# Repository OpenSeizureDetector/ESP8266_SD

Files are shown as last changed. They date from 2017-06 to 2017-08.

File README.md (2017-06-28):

# Seizure Detector Watch using DIY Hardware

A version of OpenSeizureDetector that runs on an ESP8266 wifi module.

# The Plan
*  Use a very small ESP8226 module
*  Connect an ADXL345 accelerometer using i2c interface
*  Power it from a LiPo battery
*  Use a 3D printed case to make it into a watch  
*  Software will use the esp-open-rtos FreeRTOS based ESP8266 SDK so it can be ported to other platforms more easily in the future (https://github.com/SuperHouse/esp-open-rtos).
*  Initially it will provide a web server to act as an OpenSeizureDetector 'Network Datasource' (this is likely to be too power hungry so I think we will change it to push data over wifi rather than wait for clients to ask for it in the future).

# Hardware Parts
## Feasibility and Proof-of-Concept Version
* Wemos D1 Mini ESP8226 board, with on-board USB for debugging (http://www.ebay.co.uk/itm/322463251729?_trksid=p2060353.m2749.l2649&ssPageName=STRK%3AMEBIDX%3AIT) (£5.80)
* ADXL345 module (http://www.ebay.co.uk/itm/142166117195?_trksid=p2060353.m2749.l2649&ssPageName=STRK%3AMEBIDX%3AIT) (£2.82)

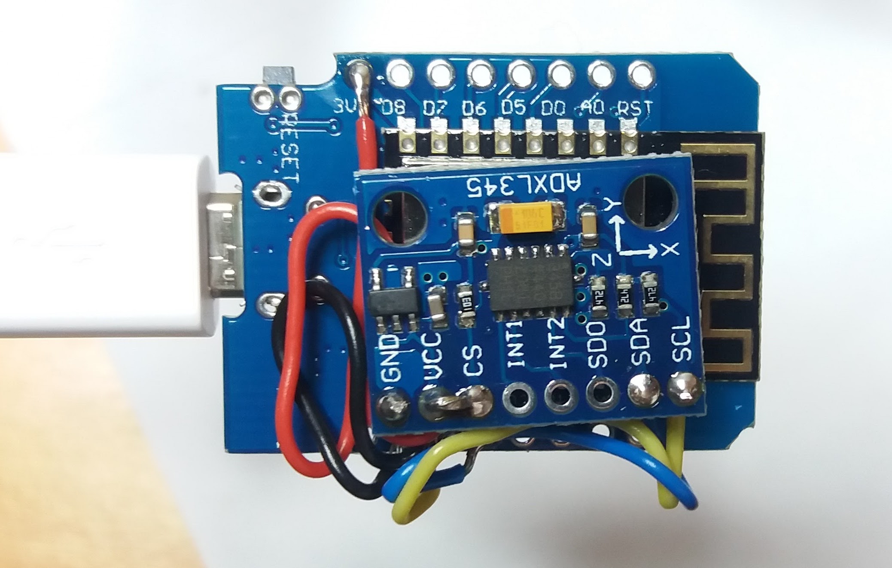
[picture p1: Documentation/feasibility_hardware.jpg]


## Prototype Version
* Small ESP8266 Board - ESP-12F (http://www.ebay.co.uk/itm/282412004710?_trksid=p2060353.m2749.l2649&ssPageName=STRK%3AMEBIDX%3AIT) (£2.52)
* ADXL345 Individual IC (http://www.ebay.co.uk/itm/132189086693?_trksid=p2060353.m2749.l2649&ssPageName=STRK%3AMEBIDX%3AIT) (£1.35)
* LiPo Battery (don't know which yet)

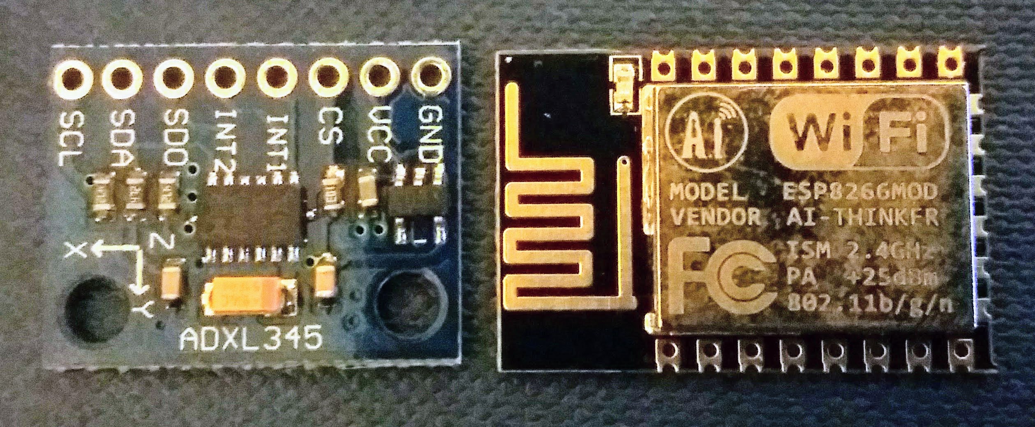
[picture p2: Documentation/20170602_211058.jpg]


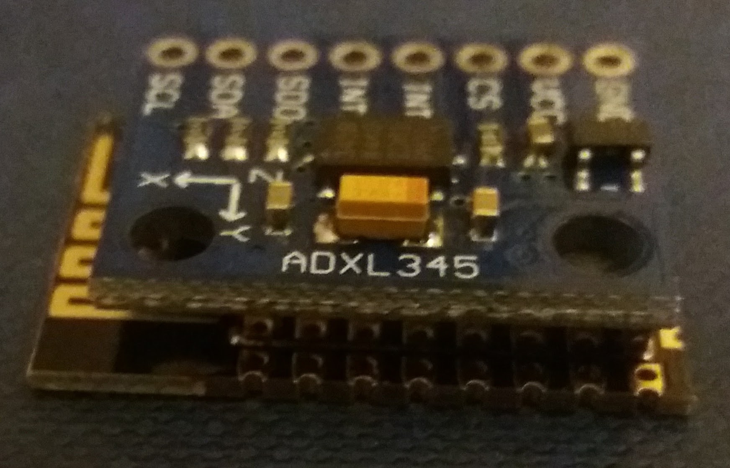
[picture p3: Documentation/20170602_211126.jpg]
Stacked Modules


# Hardware Connections
## Connect ADXL345 accelerometer to ESP8226
*  SCL  - GPIO5  (D1 on Wemos D1 Mini module)
*  SDA  - GPIO4  (D2 on Wemos D1 Mini module)
*  INT1 - GPIO13 (D7 on Wemos D1 Mini module)
*  3.3V
*  GND

No external resistors etc. are necessary.

# Development Plan
## Fesibility Study
*  Use esp-open-rtos Software Development Kit (https://github.com/SuperHouse/esp-open-rtos).
*  Use the i2c library included in the SDK.
*  Port the Arduino ADXL345 library to C and convert to use the i2c library (Complete).
*  Extend the ADXL345 library to use the FIFO register in the ADXL345 so we
   receive data in batches to save power (Complete)
*  Port the OpenSeizureDetector Pebble_SD code to use the new library, and send output to serial port for debugging (complete)
*  Add web server to prove ESP8266 capable of running seizure detector and networking simultaneously.

## Proof-of-Concept
*  Make web server act as an OpenSeizureDetector Network DataSource (in progress)
*  Test battery consumption
*  Optimise code to make battery power feasible (may involve changing from web server to ESP8266 sending data to OpenSeizureDetector alarm system)
*  Select rechargeable battery.

## Prototype
*  Make programmer hardware for ESP-12F module
*  Hand wire ADXL345 chip to ESP-12F module  
*  Connect battery
*  Design and build battery charging hardware.
*  Test
*  Produce 3D printed watch case.

# Instructions
Note that this is just at proof-of-concpt stage - don't expect it to
produce a working seizure detector!

*  Install the esp-open-rtos SDK using the instructions at https://github.com/SuperHouse/esp-open-rtos
*  Compile using
  *  cd osd_app
  *  make html  (prepare test data for web server)
  *  make  (compile software)
  *  make flash (to programme ESP8266 connected via USB)
  *  ../monitor.py (to view debugging information over serial (USB) interface).
  *  Press the reset button on the ESP8266 to view boot up and initialisation debugging information.

# Debugging
If the ESP8266 crashes because of a software bug (Such as divide by zero),
debugging information is written to the USB serial line that you can see
using monitor.py

You can find information on interpreting the crash dump at https://github.com/SuperHouse/esp-open-rtos/wiki/Crash-Dumps.

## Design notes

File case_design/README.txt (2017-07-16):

design of case for seizure detector watch

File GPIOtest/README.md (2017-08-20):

##GPIOtest
Prove we can program a Wemos D1 ESP8266 board using espressif SDK and use
GPIO.

Compile Using
source ../set_paths.sh
make
../flash_image.sh

Should flash the LED on the board....

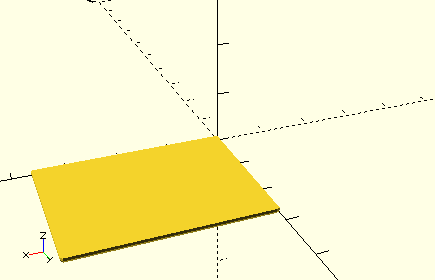
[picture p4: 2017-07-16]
case_design/lid.png

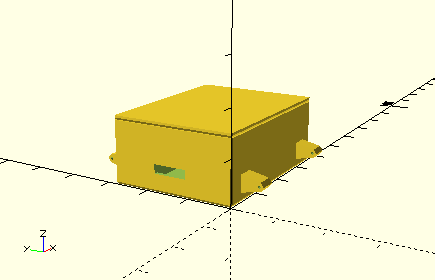
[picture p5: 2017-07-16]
case_design/case.png

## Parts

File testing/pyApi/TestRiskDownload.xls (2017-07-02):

0 | 1 | 2 | 3 | 4 | 5 | 6 | 7 | 8 | 9 | 10 | 11 | 12 | 13 | 14 | 15 | 16 | 17 | 18 | 19 | 20 | 21 | 22 | 23 | 24 | 25 | 26 | 27 | 28 | 29 | 30 | 31 | 32 | 33 | 34 | 35 | 36 | 37 | 38 | 39 | 40 | 41 | 42 | 43 | 44 | 45 | 46 | 47 | 48 | 49 | 50 | 51 | 52 | 53 | 54 | 55 | 56 | 57 | 58 | 59
Risk ID | Risk no | Parent risk id | Risk owner name | Risk owner BU | Risk title | Risk description | Risk timescales | Plant | Failure type | Lifetime issue | Problem type | Risk status | Business unit list | EPRI code list | Reactor | Risk last updated for KPI | Risk comments | Risk cause list | Risk consequences | Risk type list | Risk restricted | GRMC | CR no | Risk originator | Risk originated date | Inherent % | EPRI Code | Earliest event can happened | Latest event can happen | Most likely impact risk | Most units affected Risk | Most load reduction risk | Most downtime risk | Most cost repair risk | Most cost penalties risk | Most cost other risk | Best case impact risk | Best units affected risk | Best load reduction risk | Best downtime risk | Best cost repair risk | Best cost penalties risk | Best cost other risk | Worst case impact risk | Worst units affected risk | Worst load reduction risk | Worst downtime risk | Worst cost repair risk | Worst cost penalties risk | Worst cost other risk | Most likely non financial R1 | Most likely non financial R2 | Most likely non financial R3 | Most likely non financial R4 | Most likely non financial R5 | Most likely non financial R6 | Most likely non financial R7 | Best case non financial R1 | Best case non financial R2
127479 | R09667 (C) | R09756 (P) | Mark Pearson | PROTECTION & ELECTRICAL (HYB) | External asymmetrical grid system fault leading to loss of generation and potentially adversely affecting essential post trip equipment | 'An asymmetrical fault occurs in the grid system supplying the station leading to trip of both generators and reactors and adversely affecting the operation of motors, transformers, uninterruptible supply systems, rectifiers etc which in turn adversely affects the availability of essential post trip equipment. The asymmetrical faults include loss of one phase, loss of two phases and voltage imbalance. |  | Plant | Actual failure |  | Repeatable | Accepted | Heysham 2 | D21 GRID SYSTEMS |  | 2016-09-01 17:16 | ' | External events | ''If essential post trip equipment is lost this could in the worst case result in no forced cooling to the reactors with nuclear safety consequences. | External Events \ Disasters | No |  |  | David Lawn | 2016-01-15 11:54 | 2.00% | D21 | 2016 | 2030 | 11209512 | 2 | 100 | 10.5 | 0 | 0 | 0 | 0 | 1 | 0 | 0 | 0 | 0 | 0 | 14946016 | 2 | 100 | 10.5 | 0 | 0 | 0 |  | 2 |  | 2 |  |  |  |  | 1
127479 | R09667 (C) | R09756 (P) | Mark Pearson | PROTECTION & ELECTRICAL (HYB) | External asymmetrical grid system fault leading to loss of generation and potentially adversely affecting essential post trip equipment | 'An asymmetrical fault occurs in the grid system supplying the station leading to trip of both generators and reactors and adversely affecting the operation of motors, transformers, uninterruptible supply systems, rectifiers etc which in turn adversely affects the availability of essential post trip equipment. The asymmetrical faults include loss of one phase, loss of two phases and voltage imbalance. |  | Plant | Actual failure |  | Repeatable | Accepted | Heysham 2 | D21 GRID SYSTEMS |  | 2016-09-01 17:16 | ' | External events | ''If essential post trip equipment is lost this could in the worst case result in no forced cooling to the reactors with nuclear safety consequences. | External Events \ Disasters | No |  |  | David Lawn | 2016-01-15 11:54 | 2.00% | D21 | 2016 | 2030 | 11209512 | 2 | 100 | 10.5 | 0 | 0 | 0 | 0 | 1 | 0 | 0 | 0 | 0 | 0 | 14946016 | 2 | 100 | 10.5 | 0 | 0 | 0 |  | 2 |  | 2 |  |  |  |  | 1
127479 | R09667 (C) | R09756 (P) | Mark Pearson | PROTECTION & ELECTRICAL (HYB) | External asymmetrical grid system fault leading to loss of generation and potentially adversely affecting essential post trip equipment | 'An asymmetrical fault occurs in the grid system supplying the station leading to trip of both generators and reactors and adversely affecting the operation of motors, transformers, uninterruptible supply systems, rectifiers etc which in turn adversely affects the availability of essential post trip equipment. The asymmetrical faults include loss of one phase, loss of two phases and voltage imbalance. |  | Plant | Actual failure |  | Repeatable | Accepted | Heysham 2 | D21 GRID SYSTEMS |  | 2016-09-01 17:16 | ' | External events | ''If essential post trip equipment is lost this could in the worst case result in no forced cooling to the reactors with nuclear safety consequences. | External Events \ Disasters | No |  |  | David Lawn | 2016-01-15 11:54 | 2.00% | D21 | 2016 | 2030 | 11209512 | 2 | 100 | 10.5 | 0 | 0 | 0 | 0 | 1 | 0 | 0 | 0 | 0 | 0 | 14946016 | 2 | 100 | 10.5 | 0 | 0 | 0 |  | 2 |  | 2 |  |  |  |  | 1
127479 | R09667 (C) | R09756 (P) | Mark Pearson | PROTECTION & ELECTRICAL (HYB) | External asymmetrical grid system fault leading to loss of generation and potentially adversely affecting essential post trip equipment | 'An asymmetrical fault occurs in the grid system supplying the station leading to trip of both generators and reactors and adversely affecting the operation of motors, transformers, uninterruptible supply systems, rectifiers etc which in turn adversely affects the availability of essential post trip equipment. The asymmetrical faults include loss of one phase, loss of two phases and voltage imbalance. |  | Plant | Actual failure |  | Repeatable | Accepted | Heysham 2 | D21 GRID SYSTEMS |  | 2016-09-01 17:16 | ' | External events | ''If essential post trip equipment is lost this could in the worst case result in no forced cooling to the reactors with nuclear safety consequences. | External Events \ Disasters | No |  |  | David Lawn | 2016-01-15 11:54 | 2.00% | D21 | 2016 | 2030 | 11209512 | 2 | 100 | 10.5 | 0 | 0 | 0 | 0 | 1 | 0 | 0 | 0 | 0 | 0 | 14946016 | 2 | 100 | 10.5 | 0 | 0 | 0 |  | 2 |  | 2 |  |  |  |  | 1
127473 | R09668 (C) | R09756 (P) | Andy Palin | PROTECTION & ELECTRICAL (HYA) | External asymmetrical grid system fault leading to loss of generation and potentially adversely affecting essential post trip equipment | 'An asymmetrical fault occurs in the grid system supplying the station leading to trip of both generators and reactors and adversely affecting the operation of motors, transformers, uninterruptible supply systems, rectifiers etc which in turn adversely affects the availability of essential post trip equipment. The asymmetrical faults include loss of one phase, loss of two phases and voltage imbalance. |  | Plant | Actual failure |  | Repeatable | Addressing | Heysham 1 | D21 GRID SYSTEMS |  | 2016-09-01 17:21 | ''Mitigations updated CH 07/16 | External events | ''If essential post trip equipment is lost this could in the worst case result in no forced cooling to the reactors with nuclear safety consequences. | External Events \ Disasters | No |  |  | David Lawn | 2016-01-15 11:45 | 2.00% | D21 | 2016 | 2024 | 10350871 | 2 | 100 | 10.5 | 0 | 0 | 0 | 0 | 1 | 0 | 0 | 0 | 0 | 0 | 13801162 | 2 | 100 | 10.5 | 0 | 0 | 0 |  | 2 |  | 2 |  |  |  |  | 1
127473 | R09668 (C) | R09756 (P) | Andy Palin | PROTECTION & ELECTRICAL (HYA) | External asymmetrical grid system fault leading to loss of generation and potentially adversely affecting essential post trip equipment | 'An asymmetrical fault occurs in the grid system supplying the station leading to trip of both generators and reactors and adversely affecting the operation of motors, transformers, uninterruptible supply systems, rectifiers etc which in turn adversely affects the availability of essential post trip equipment. The asymmetrical faults include loss of one phase, loss of two phases and voltage imbalance. |  | Plant | Actual failure |  | Repeatable | Addressing | Heysham 1 | D21 GRID SYSTEMS |  | 2016-09-01 17:21 | ''Mitigations updated CH 07/16 | External events | ''If essential post trip equipment is lost this could in the worst case result in no forced cooling to the reactors with nuclear safety consequences. | External Events \ Disasters | No |  |  | David Lawn | 2016-01-15 11:45 | 2.00% | D21 | 2016 | 2024 | 10350871 | 2 | 100 | 10.5 | 0 | 0 | 0 | 0 | 1 | 0 | 0 | 0 | 0 | 0 | 13801162 | 2 | 100 | 10.5 | 0 | 0 | 0 |  | 2 |  | 2 |  |  |  |  | 1
127473 | R09668 (C) | R09756 (P) | Andy Palin | PROTECTION & ELECTRICAL (HYA) | External asymmetrical grid system fault leading to loss of generation and potentially adversely affecting essential post trip equipment | 'An asymmetrical fault occurs in the grid system supplying the station leading to trip of both generators and reactors and adversely affecting the operation of motors, transformers, uninterruptible supply systems, rectifiers etc which in turn adversely affects the availability of essential post trip equipment. The asymmetrical faults include loss of one phase, loss of two phases and voltage imbalance. |  | Plant | Actual failure |  | Repeatable | Addressing | Heysham 1 | D21 GRID SYSTEMS |  | 2016-09-01 17:21 | ''Mitigations updated CH 07/16 | External events | ''If essential post trip equipment is lost this could in the worst case result in no forced cooling to the reactors with nuclear safety consequences. | External Events \ Disasters | No |  |  | David Lawn | 2016-01-15 11:45 | 2.00% | D21 | 2016 | 2024 | 10350871 | 2 | 100 | 10.5 | 0 | 0 | 0 | 0 | 1 | 0 | 0 | 0 | 0 | 0 | 13801162 | 2 | 100 | 10.5 | 0 | 0 | 0 |  | 2 |  | 2 |  |  |  |  | 1
127473 | R09668 (C) | R09756 (P) | Andy Palin | PROTECTION & ELECTRICAL (HYA) | External asymmetrical grid system fault leading to loss of generation and potentially adversely affecting essential post trip equipment | 'An asymmetrical fault occurs in the grid system supplying the station leading to trip of both generators and reactors and adversely affecting the operation of motors, transformers, uninterruptible supply systems, rectifiers etc which in turn adversely affects the availability of essential post trip equipment. The asymmetrical faults include loss of one phase, loss of two phases and voltage imbalance. |  | Plant | Actual failure |  | Repeatable | Addressing | Heysham 1 | D21 GRID SYSTEMS |  | 2016-09-01 17:21 | ''Mitigations updated CH 07/16 | External events | ''If essential post trip equipment is lost this could in the worst case result in no forced cooling to the reactors with nuclear safety consequences. | External Events \ Disasters | No |  |  | David Lawn | 2016-01-15 11:45 | 2.00% | D21 | 2016 | 2024 | 10350871 | 2 | 100 | 10.5 | 0 | 0 | 0 | 0 | 1 | 0 | 0 | 0 | 0 | 0 | 13801162 | 2 | 100 | 10.5 | 0 | 0 | 0 |  | 2 |  | 2 |  |  |  |  | 1
127489 | R09669 (C) | R09756 (P) | Andy Cook | PROTECTION & ELECTRICAL (SZB) | External asymmetrical grid system fault leading to loss of generation and potentially adversely affecting essential post trip equipment | 'An asymmetrical fault occurs in the grid system supplying the station leading to generator and reactor trip and adversely affecting the operation of motors, transformers, uninterruptible supply systems, rectifiers etc which in turn adversely affects the availability of essential post trip equipment. The asymmetrical faults include loss of one phase, loss of two phases and voltage imbalance. |  | Plant | Actual failure |  | Repeatable | Accepted | Sizewell B | D21 GRID SYSTEMS |  | 2016-10-03 15:34 | ' | External events | ''If essential post trip equipment is lost this could in the worst case result in no forced cooling to the reactors with nuclear safety consequences. | External Events \ Disasters | No |  |  | David Lawn | 2016-01-15 14:01 | 2.00% | D21 | 2016 | 2055 | 11391148 | 2 | 100 | 10.5 | 0 | 0 | 0 | 0 | 1 | 0 | 0 | 0 | 0 | 0 | 15188197 | 2 | 100 | 10.5 | 0 | 0 | 0 |  | 2 |  | 2 |  |  |  |  | 1
127489 | R09669 (C) | R09756 (P) | Andy Cook | PROTECTION & ELECTRICAL (SZB) | External asymmetrical grid system fault leading to loss of generation and potentially adversely affecting essential post trip equipment | 'An asymmetrical fault occurs in the grid system supplying the station leading to generator and reactor trip and adversely affecting the operation of motors, transformers, uninterruptible supply systems, rectifiers etc which in turn adversely affects the availability of essential post trip equipment. The asymmetrical faults include loss of one phase, loss of two phases and voltage imbalance. |  | Plant | Actual failure |  | Repeatable | Accepted | Sizewell B | D21 GRID SYSTEMS |  | 2016-10-03 15:34 | ' | External events | ''If essential post trip equipment is lost this could in the worst case result in no forced cooling to the reactors with nuclear safety consequences. | External Events \ Disasters | No |  |  | David Lawn | 2016-01-15 14:01 | 2.00% | D21 | 2016 | 2055 | 11391148 | 2 | 100 | 10.5 | 0 | 0 | 0 | 0 | 1 | 0 | 0 | 0 | 0 | 0 | 15188197 | 2 | 100 | 10.5 | 0 | 0 | 0 |  | 2 |  | 2 |  |  |  |  | 1
127489 | R09669 (C) | R09756 (P) | Andy Cook | PROTECTION & ELECTRICAL (SZB) | External asymmetrical grid system fault leading to loss of generation and potentially adversely affecting essential post trip equipment | 'An asymmetrical fault occurs in the grid system supplying the station leading to generator and reactor trip and adversely affecting the operation of motors, transformers, uninterruptible supply systems, rectifiers etc which in turn adversely affects the availability of essential post trip equipment. The asymmetrical faults include loss of one phase, loss of two phases and voltage imbalance. |  | Plant | Actual failure |  | Repeatable | Accepted | Sizewell B | D21 GRID SYSTEMS |  | 2016-10-03 15:34 | ' | External events | ''If essential post trip equipment is lost this could in the worst case result in no forced cooling to the reactors with nuclear safety consequences. | External Events \ Disasters | No |  |  | David Lawn | 2016-01-15 14:01 | 2.00% | D21 | 2016 | 2055 | 11391148 | 2 | 100 | 10.5 | 0 | 0 | 0 | 0 | 1 | 0 | 0 | 0 | 0 | 0 | 15188197 | 2 | 100 | 10.5 | 0 | 0 | 0 |  | 2 |  | 2 |  |  |  |  | 1
127489 | R09669 (C) | R09756 (P) | Andy Cook | PROTECTION & ELECTRICAL (SZB) | External asymmetrical grid system fault leading to loss of generation and potentially adversely affecting essential post trip equipment | 'An asymmetrical fault occurs in the grid system supplying the station leading to generator and reactor trip and adversely affecting the operation of motors, transformers, uninterruptible supply systems, rectifiers etc which in turn adversely affects the availability of essential post trip equipment. The asymmetrical faults include loss of one phase, loss of two phases and voltage imbalance. |  | Plant | Actual failure |  | Repeatable | Accepted | Sizewell B | D21 GRID SYSTEMS |  | 2016-10-03 15:34 | ' | External events | ''If essential post trip equipment is lost this could in the worst case result in no forced cooling to the reactors with nuclear safety consequences. | External Events \ Disasters | No |  |  | David Lawn | 2016-01-15 14:01 | 2.00% | D21 | 2016 | 2055 | 11391148 | 2 | 100 | 10.5 | 0 | 0 | 0 | 0 | 1 | 0 | 0 | 0 | 0 | 0 | 15188197 | 2 | 100 | 10.5 | 0 | 0 | 0 |  | 2 |  | 2 |  |  |  |  | 1
127477 | R09670 (C) | R09756 (P) | James Purss | COMPONENT & PROGRAMME ENGINEERS* (HNB) | External asymmetrical grid system fault leading to loss of generation and potentially adversely affecting essential post trip equipment | 'An asymmetrical fault occurs in the grid system supplying the station leading to trip of both generators and reactors and adversely affecting the operation of motors, transformers, uninterruptible supply systems, rectifiers etc which in turn adversely affects the availability of essential post trip equipment. The asymmetrical faults include loss of one phase, loss of two phases and voltage imbalance. |  | Plant | Actual failure |  | Repeatable | Accepted | Hunterston B | D21 GRID SYSTEMS |  | 2016-09-01 17:24 | ''Ryan Doherty accepted on Behalf of Station following conversations with relevant station personnel in the absense of Group Head. | External events | ''If essential post trip equipment is lost this could in the worst case result in no forced cooling to the reactors with nuclear safety consequences. | External Events \ Disasters | No |  |  | David Lawn | 2016-01-15 11:50 | 2.00% | D21 | 2016 | 2023 | 8548668 | 2 | 100 | 10.5 | 0 | 0 | 0 | 0 | 1 | 0 | 0 | 0 | 0 | 0 | 11398225 | 2 | 100 | 10.5 | 0 | 0 | 0 |  | 2 |  | 2 |  |  |  |  | 1
127477 | R09670 (C) | R09756 (P) | James Purss | COMPONENT & PROGRAMME ENGINEERS* (HNB) | External asymmetrical grid system fault leading to loss of generation and potentially adversely affecting essential post trip equipment | 'An asymmetrical fault occurs in the grid system supplying the station leading to trip of both generators and reactors and adversely affecting the operation of motors, transformers, uninterruptible supply systems, rectifiers etc which in turn adversely affects the availability of essential post trip equipment. The asymmetrical faults include loss of one phase, loss of two phases and voltage imbalance. |  | Plant | Actual failure |  | Repeatable | Accepted | Hunterston B | D21 GRID SYSTEMS |  | 2016-09-01 17:24 | ''Ryan Doherty accepted on Behalf of Station following conversations with relevant station personnel in the absense of Group Head. | External events | ''If essential post trip equipment is lost this could in the worst case result in no forced cooling to the reactors with nuclear safety consequences. | External Events \ Disasters | No |  |  | David Lawn | 2016-01-15 11:50 | 2.00% | D21 | 2016 | 2023 | 8548668 | 2 | 100 | 10.5 | 0 | 0 | 0 | 0 | 1 | 0 | 0 | 0 | 0 | 0 | 11398225 | 2 | 100 | 10.5 | 0 | 0 | 0 |  | 2 |  | 2 |  |  |  |  | 1
127477 | R09670 (C) | R09756 (P) | James Purss | COMPONENT & PROGRAMME ENGINEERS* (HNB) | External asymmetrical grid system fault leading to loss of generation and potentially adversely affecting essential post trip equipment | 'An asymmetrical fault occurs in the grid system supplying the station leading to trip of both generators and reactors and adversely affecting the operation of motors, transformers, uninterruptible supply systems, rectifiers etc which in turn adversely affects the availability of essential post trip equipment. The asymmetrical faults include loss of one phase, loss of two phases and voltage imbalance. |  | Plant | Actual failure |  | Repeatable | Accepted | Hunterston B | D21 GRID SYSTEMS |  | 2016-09-01 17:24 | ''Ryan Doherty accepted on Behalf of Station following conversations with relevant station personnel in the absense of Group Head. | External events | ''If essential post trip equipment is lost this could in the worst case result in no forced cooling to the reactors with nuclear safety consequences. | External Events \ Disasters | No |  |  | David Lawn | 2016-01-15 11:50 | 2.00% | D21 | 2016 | 2023 | 8548668 | 2 | 100 | 10.5 | 0 | 0 | 0 | 0 | 1 | 0 | 0 | 0 | 0 | 0 | 11398225 | 2 | 100 | 10.5 | 0 | 0 | 0 |  | 2 |  | 2 |  |  |  |  | 1
127477 | R09670 (C) | R09756 (P) | James Purss | COMPONENT & PROGRAMME ENGINEERS* (HNB) | External asymmetrical grid system fault leading to loss of generation and potentially adversely affecting essential post trip equipment | 'An asymmetrical fault occurs in the grid system supplying the station leading to trip of both generators and reactors and adversely affecting the operation of motors, transformers, uninterruptible supply systems, rectifiers etc which in turn adversely affects the availability of essential post trip equipment. The asymmetrical faults include loss of one phase, loss of two phases and voltage imbalance. |  | Plant | Actual failure |  | Repeatable | Accepted | Hunterston B | D21 GRID SYSTEMS |  | 2016-09-01 17:24 | ''Ryan Doherty accepted on Behalf of Station following conversations with relevant station personnel in the absense of Group Head. | External events | ''If essential post trip equipment is lost this could in the worst case result in no forced cooling to the reactors with nuclear safety consequences. | External Events \ Disasters | No |  |  | David Lawn | 2016-01-15 11:50 | 2.00% | D21 | 2016 | 2023 | 8548668 | 2 | 100 | 10.5 | 0 | 0 | 0 | 0 | 1 | 0 | 0 | 0 | 0 | 0 | 11398225 | 2 | 100 | 10.5 | 0 | 0 | 0 |  | 2 |  | 2 |  |  |  |  | 1
127469 | R09671 (C) | R09756 (P) | Jon Back | PROTECTION & ELECTRICAL - SYSTEM HEALTH (DNB) | External asymmetrical grid system fault leading to loss of generation and potentially adversely affecting essential post trip equipment | 'An asymmetrical fault occurs in the grid system supplying the station leading to trip of both generators and reactors and adversely affecting the operation of motors, transformers, uninterruptible supply systems, rectifiers etc which in turn adversely affects the availability of essential post trip equipment. The asymmetrical faults include loss of one phase, loss of two phases and voltage imbalance. |  | Plant | Actual failure |  | Repeatable | Accepted | Dungeness B | D21 GRID SYSTEMS |  | 2016-09-01 17:17 | ' | External events | ''If essential post trip equipment is lost this could in the worst case result in no forced cooling to the reactors with nuclear safety consequences. | External Events \ Disasters | No |  |  | David Lawn | 2016-01-15 11:32 | 2.00% | D21 | 2016 | 2028 | 8119348 | 2 | 100 | 10.5 | 0 | 0 | 0 | 0 | 1 | 0 | 0 | 0 | 0 | 0 | 10825797 | 2 | 100 | 10.5 | 0 | 0 | 0 |  | 2 |  | 2 |  |  |  |  | 1
127469 | R09671 (C) | R09756 (P) | Jon Back | PROTECTION & ELECTRICAL - SYSTEM HEALTH (DNB) | External asymmetrical grid system fault leading to loss of generation and potentially adversely affecting essential post trip equipment | 'An asymmetrical fault occurs in the grid system supplying the station leading to trip of both generators and reactors and adversely affecting the operation of motors, transformers, uninterruptible supply systems, rectifiers etc which in turn adversely affects the availability of essential post trip equipment. The asymmetrical faults include loss of one phase, loss of two phases and voltage imbalance. |  | Plant | Actual failure |  | Repeatable | Accepted | Dungeness B | D21 GRID SYSTEMS |  | 2016-09-01 17:17 | ' | External events | ''If essential post trip equipment is lost this could in the worst case result in no forced cooling to the reactors with nuclear safety consequences. | External Events \ Disasters | No |  |  | David Lawn | 2016-01-15 11:32 | 2.00% | D21 | 2016 | 2028 | 8119348 | 2 | 100 | 10.5 | 0 | 0 | 0 | 0 | 1 | 0 | 0 | 0 | 0 | 0 | 10825797 | 2 | 100 | 10.5 | 0 | 0 | 0 |  | 2 |  | 2 |  |  |  |  | 1
127469 | R09671 (C) | R09756 (P) | Jon Back | PROTECTION & ELECTRICAL - SYSTEM HEALTH (DNB) | External asymmetrical grid system fault leading to loss of generation and potentially adversely affecting essential post trip equipment | 'An asymmetrical fault occurs in the grid system supplying the station leading to trip of both generators and reactors and adversely affecting the operation of motors, transformers, uninterruptible supply systems, rectifiers etc which in turn adversely affects the availability of essential post trip equipment. The asymmetrical faults include loss of one phase, loss of two phases and voltage imbalance. |  | Plant | Actual failure |  | Repeatable | Accepted | Dungeness B | D21 GRID SYSTEMS |  | 2016-09-01 17:17 | ' | External events | ''If essential post trip equipment is lost this could in the worst case result in no forced cooling to the reactors with nuclear safety consequences. | External Events \ Disasters | No |  |  | David Lawn | 2016-01-15 11:32 | 2.00% | D21 | 2016 | 2028 | 8119348 | 2 | 100 | 10.5 | 0 | 0 | 0 | 0 | 1 | 0 | 0 | 0 | 0 | 0 | 10825797 | 2 | 100 | 10.5 | 0 | 0 | 0 |  | 2 |  | 2 |  |  |  |  | 1
127469 | R09671 (C) | R09756 (P) | Jon Back | PROTECTION & ELECTRICAL - SYSTEM HEALTH (DNB) | External asymmetrical grid system fault leading to loss of generation and potentially adversely affecting essential post trip equipment | 'An asymmetrical fault occurs in the grid system supplying the station leading to trip of both generators and reactors and adversely affecting the operation of motors, transformers, uninterruptible supply systems, rectifiers etc which in turn adversely affects the availability of essential post trip equipment. The asymmetrical faults include loss of one phase, loss of two phases and voltage imbalance. |  | Plant | Actual failure |  | Repeatable | Accepted | Dungeness B | D21 GRID SYSTEMS |  | 2016-09-01 17:17 | ' | External events | ''If essential post trip equipment is lost this could in the worst case result in no forced cooling to the reactors with nuclear safety consequences. | External Events \ Disasters | No |  |  | David Lawn | 2016-01-15 11:32 | 2.00% | D21 | 2016 | 2028 | 8119348 | 2 | 100 | 10.5 | 0 | 0 | 0 | 0 | 1 | 0 | 0 | 0 | 0 | 0 | 10825797 | 2 | 100 | 10.5 | 0 | 0 | 0 |  | 2 |  | 2 |  |  |  |  | 1
127485 | R09672 (C) | R09756 (P) | Graeme Smillie | PROTECTION & ELECTRICAL (TOR) | External asymmetrical grid system fault leading to loss of generation and potentially adversely affecting essential post trip equipment | 'An asymmetrical fault occurs in the grid system supplying the station leading to trip of both generators and reactors and adversely affecting the operation of motors, transformers, uninterruptible supply systems, rectifiers etc which in turn adversely affects the availability of essential post trip equipment. The asymmetrical faults include loss of one phase, loss of two phases and voltage imbalance. |  | Plant | Actual failure |  | Repeatable | Accepted | Torness | D21 GRID SYSTEMS |  | 2016-09-01 17:14 | ''IJCO has been written for Torness, recently extended to allow INSA assessment of the JCO 354698. External contractor looking at options for installing bespoke meter. Initial survey carried out. 29.06.16 | External events | ''If essential post trip equipment is lost this could in the worst case result in no forced cooling to the reactors with nuclear safety consequences. | External Events \ Disasters | No |  |  | David Lawn | 2016-01-15 13:36 | 2.00% | D21 | 2016 | 2030 | 11221307 | 2 | 100 | 10.5 | 0 | 0 | 0 | 0 | 1 | 0 | 0 | 0 | 0 | 0 | 14961742 | 2 | 100 | 10.5 | 0 | 0 | 0 |  | 2 |  | 2 |  |  |  |  | 1
127485 | R09672 (C) | R09756 (P) | Graeme Smillie | PROTECTION & ELECTRICAL (TOR) | External asymmetrical grid system fault leading to loss of generation and potentially adversely affecting essential post trip equipment | 'An asymmetrical fault occurs in the grid system supplying the station leading to trip of both generators and reactors and adversely affecting the operation of motors, transformers, uninterruptible supply systems, rectifiers etc which in turn adversely affects the availability of essential post trip equipment. The asymmetrical faults include loss of one phase, loss of two phases and voltage imbalance. |  | Plant | Actual failure |  | Repeatable | Accepted | Torness | D21 GRID SYSTEMS |  | 2016-09-01 17:14 | ''IJCO has been written for Torness, recently extended to allow INSA assessment of the JCO 354698. External contractor looking at options for installing bespoke meter. Initial survey carried out. 29.06.16 | External events | ''If essential post trip equipment is lost this could in the worst case result in no forced cooling to the reactors with nuclear safety consequences. | External Events \ Disasters | No |  |  | David Lawn | 2016-01-15 13:36 | 2.00% | D21 | 2016 | 2030 | 11221307 | 2 | 100 | 10.5 | 0 | 0 | 0 | 0 | 1 | 0 | 0 | 0 | 0 | 0 | 14961742 | 2 | 100 | 10.5 | 0 | 0 | 0 |  | 2 |  | 2 |  |  |  |  | 1
127485 | R09672 (C) | R09756 (P) | Graeme Smillie | PROTECTION & ELECTRICAL (TOR) | External asymmetrical grid system fault leading to loss of generation and potentially adversely affecting essential post trip equipment | 'An asymmetrical fault occurs in the grid system supplying the station leading to trip of both generators and reactors and adversely affecting the operation of motors, transformers, uninterruptible supply systems, rectifiers etc which in turn adversely affects the availability of essential post trip equipment. The asymmetrical faults include loss of one phase, loss of two phases and voltage imbalance. |  | Plant | Actual failure |  | Repeatable | Accepted | Torness | D21 GRID SYSTEMS |  | 2016-09-01 17:14 | ''IJCO has been written for Torness, recently extended to allow INSA assessment of the JCO 354698. External contractor looking at options for installing bespoke meter. Initial survey carried out. 29.06.16 | External events | ''If essential post trip equipment is lost this could in the worst case result in no forced cooling to the reactors with nuclear safety consequences. | External Events \ Disasters | No |  |  | David Lawn | 2016-01-15 13:36 | 2.00% | D21 | 2016 | 2030 | 11221307 | 2 | 100 | 10.5 | 0 | 0 | 0 | 0 | 1 | 0 | 0 | 0 | 0 | 0 | 14961742 | 2 | 100 | 10.5 | 0 | 0 | 0 |  | 2 |  | 2 |  |  |  |  | 1
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

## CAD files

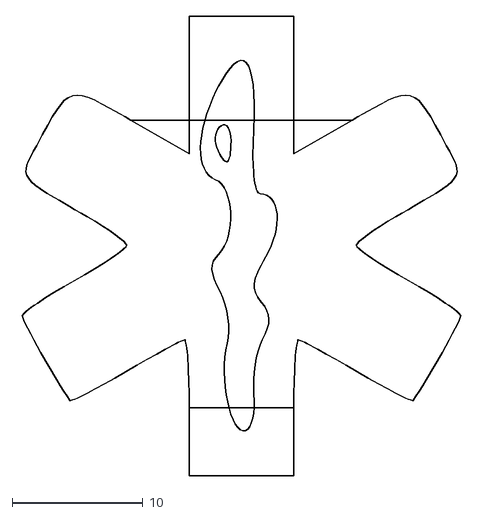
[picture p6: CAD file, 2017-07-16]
case_design/OSD_Logo.dxf
34.5 x 35.2

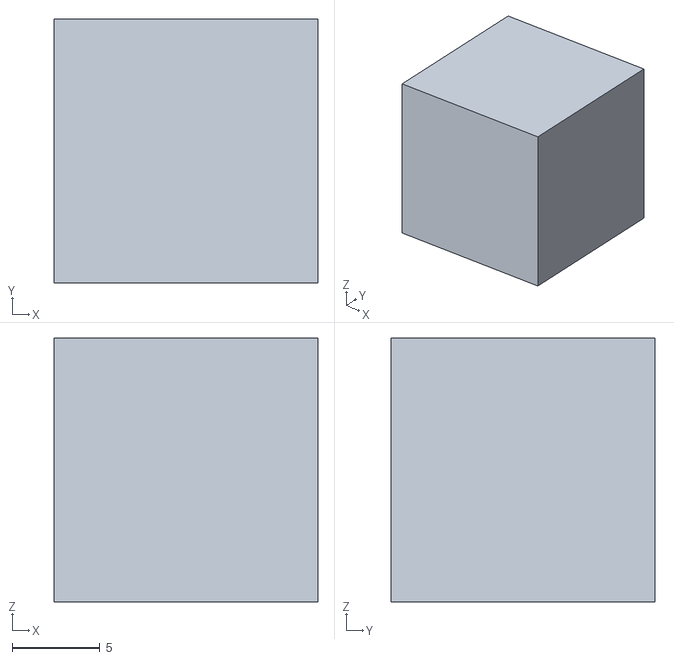
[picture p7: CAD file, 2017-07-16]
case_design/TestCube.stl
15.0 x 15.0 x 15.0

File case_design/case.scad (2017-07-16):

include <dimensions.scad>;

x=Cx+(2*b);    //case size
y=Cy+(2*b);
z=Cz+Bz+b;

intersection() {
    difference() {
        translate([r,r,r]) hull() {
            sphere(r);
            translate([x-(2*r),0,0]) sphere(r);
            translate([0,y-(2*r),0]) sphere(r);
            translate([0,0,z-r]) sphere(r);
            translate([x-(2*r),y-(2*r),0]) sphere(r);
            translate([x-(2*r),0,z-r]) sphere(r);
            translate([0,y-(2*r),z-r]) sphere(r);
            translate([x-(2*r),y-(2*r),z-r]) sphere(r);
        }

        translate([b,b,b]) cube([Bx,By,Bz+0.1]);
        translate([b,b,b+Bz]) cube([Cx,Cy,Cz+0.1]);
        translate([-0.1,b+9.5,b+Bz]) cube([b+0.2,7.5,2]);
    
    }
    cube([x,y,z]);
}

module lug() {
    
    difference() {
        intersection() {

            linear_extrude(height=3.5) {
                hull() {
                    circle(2);
                    translate([4,0,1]) circle(1);
                }
            }
            translate([0,-2,0]) cube([5,4,3.5]);
        }
        translate([4,0,-0.1]) cylinder(r=0.35, h=3.7);
    }
}

translate([((x-22)/2)-3.5,-0.1,4]) rotate([90,180,90]) lug();
translate([((x-22)/2)+22,-0.1,4]) rotate([90,180,90]) lug();
translate([((x-22)/2),y-0.1,4]) rotate([90,180,270]) lug();
translate([((x-22)/2)+25.5,y-0.1,4]) rotate([90,180,270]) lug();


    

    

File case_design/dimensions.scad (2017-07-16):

Bx=30;     //battery size
By=20;
Bz=3;

Cx=34.5;     //circuit size
Cy=26;
Cz=10;

b=1;    //border width
r=0.5;    //radius of curvature

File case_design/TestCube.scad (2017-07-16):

cube(15, center=true);

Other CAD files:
case_design/lid.scad
case_design/textTest.scad

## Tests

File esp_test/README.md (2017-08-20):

esp_test
========

Simple app to prove we can program an ESP8266 using the espressif esp-open-rtos SDK.

Compile using
source ../set_paths.sh
make
../flash_image.sh

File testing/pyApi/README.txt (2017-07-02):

pyAPI README
============

This folder contains a simple python based web server to store
and retrieve risks and mitigations in an sqlite database.

The schema is very simple - very little data is stored in database
columns with most data stored as a single json blob.

The advantage of this is that we can change the database schema
easily during development.
The disadvantage is that it is likely to be slower because we need
to interpret the json blob for each risk or mitigation to apply
filters on fields that are not stored as rows.
For this reason the following data is stored as database table rows:

ID - unique id of the risk. (integer)
riskNo - NGRL risk number   (String)
type - R or M for risk or mitigation (String)
bu - business unit   (String)
epri - epri code   (String)
title - risk title   (String)
parent - the unique ID of the parent.
data - complete data for risk/mitigation as a json blob.

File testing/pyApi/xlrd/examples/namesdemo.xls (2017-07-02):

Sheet: Sheet1
42

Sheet: Sheet3
 | Jan | Feb | Mar | Apr | May | Jun | Jul | Aug | Sep | Oct | Nov | Dec | Year Tot
Sales
Expenses
Profit |  |  |  |  |  |  |  |  |  |  |  | 4321 | 9876
4321
9876
1 | 2 | 4 | 8
16 | 32 | 64 | 128 | 256 | 512
 |  | 1024 | 2048 | 4096 | 8192
16383 | 16383
192 | 192
16575 | 16575
TRUE
FALSE
65536
65535
-1
 |  | 579 |  | TRUE
ascii |  | 123456 |  | FALSE
 |  | 123456 |  | FALSE
αβγδε |  | 12.3456.789 |  | TRUE
2006-12-07 |  | 12.3456.789
 |  |  |  | 256

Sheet: Seamus O'Reilly
42

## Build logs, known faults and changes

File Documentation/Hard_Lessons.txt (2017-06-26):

Hard Lessons in ESP8266 and ADXL345
===================================

...As learned during development of this project...

1.  ESP8266 is system on a chip.  This is usually bought as part of a module on a PCB.   The ESP8266 GPIO numbers often bear no resemblance to the D0,D1 etc. numbers on the module PCB!! (See https://wiki.wemos.cc/products:d1:d1_mini as an example).

2.  GPIOs 0, 2 and 15 are special and putting signals on them during boot can stop the device booting - Only use them as outputs to be safe!!! (http://www.forward.com.au/pfod/ESP8266/GPIOpins/index.html)

3.  There are many programmin environments (SDKs) for ESP8266.  Sample code that
works with one SDK is highly unlikely to work with another, so knowing which SDK the example is for is very important.

4.  To avoid overloading the system with interrupts, it is good to have interrupts triggering on edges rather than pin values but if the ESP8266 boots with the interupt pin in the 'active' state, the interrupt will not fire (For example if the 'data ready' interrupt on the ADXL345 is present by the time the ESP8266 has initialised - avoid this by doing a manual read from the ESP8266 to clear any interupts following ESP8266 initialisation.

5.  If you blow up an ADXL345 INT output, it is very hard to track down the fault because you think you have made a mistake in the software!  (I only spotted it by measuring the voltage and saw it was peculiar - neither high nor low...).  The rest of the chip was working ok, but no interrupts generated.

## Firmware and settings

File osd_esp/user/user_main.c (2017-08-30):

/*
 * OpenSeizureDetector - ESP8266 Version.
 *  ADXL code based on https://gist.github.com/shunkino/6b1734ee892fe2efbd12
 *  GPIO code based on https://github.com/espressif/esp8266-rtos-sample-code/tree/master/02Peripheral/GPIOtest
 */

#include <freertos/FreeRTOS.h>
#include <freertos/queue.h>
#include "esp_common.h"
#include "gpio.h"
#include "i2c.h"
#include "adxl345.h"
#include "osd_app.h"

// Define which GPIO pins are used to connect to the ADXL345 accelerometer.
//#define SCL_PIN (5)  // Wemos D1 Mini D1 = GPIO5
//#define SDA_PIN (4)  // Wemos D1 Mini D2 = GPIO4
//#define INTR_PIN (13) // Wemos D1 Mini D7 = GPIO13
//#define SETUP_PIN (12)  // Wemos D1 Mini D6 = GPIO12

//GPIO OUTPUT SETTINGS
#define  LED_IO_NUM  2
#define  LED_IO_FUNC FUNC_GPIO2
#define  LED_IO_PIN  GPIO_Pin_2

//GPIO INPUT SETTINGS
#define  BUTTON_IO_NUM   12
#define  BUTTON_IO_FUNC  FUNC_GPIO12
#define  BUTTON_IO_PIN   GPIO_Pin_12

#define ACC_BUF_LEN 50


/* GLOBAL VARIABLES */
int debug = 1;
Sd_Settings sdS;        // SD setings structure.
Wifi_Settings wifiS;    // Wifi Settings structure.

static xQueueHandle tsqueue;
static xQueueHandle commsQueue;


void settings_init() {
  sdS.samplePeriod = SAMPLE_PERIOD_DEFAULT;
  sdS.sampleFreq = SAMPLE_FREQ_DEFAULT;
  sdS.freqCutoff = FREQ_CUTOFF_DEFAULT;
  sdS.dataUpdatePeriod = DATA_UPDATE_PERIOD_DEFAULT;
  sdS.sdMode = SD_MODE_DEFAULT;
  sdS.alarmFreqMin = ALARM_FREQ_MIN_DEFAULT;
  sdS.alarmFreqMax = ALARM_FREQ_MAX_DEFAULT;
  sdS.warnTime = WARN_TIME_DEFAULT;
  sdS.alarmTime = ALARM_TIME_DEFAULT;
  sdS.alarmThresh = ALARM_THRESH_DEFAULT;
  sdS.alarmRatioThresh = ALARM_RATIO_THRESH_DEFAULT;
  sdS.fallActive = FALL_ACTIVE_DEFAULT;
  sdS.fallThreshMin = FALL_THRESH_MIN_DEFAULT;
  sdS.fallThreshMax = FALL_THRESH_MAX_DEFAULT;
  sdS.fallWindow = FALL_WINDOW_DEFAULT;
}


/******************************************************************************
 * FunctionName : user_rf_cal_sector_set
 * Description  : SDK just reversed 4 sectors, used for rf init data and paramters.
 *                We add this function to force users to set rf cal sector, since
 *                we don't know which sector is free in user's application.
 *                sector map for last several sectors : ABCCC
 *                A : rf cal
 *                B : rf init data
 *                C : sdk parameters
 * Parameters   : none
 * Returns      : rf cal sector
 *******************************************************************************/
uint32 user_rf_cal_sector_set(void)
{
    flash_size_map size_map = system_get_flash_size_map();
    uint32 rf_cal_sec = 0;

    switch (size_map) {
        case FLASH_SIZE_4M_MAP_256_256:
            rf_cal_sec = 128 - 5;
            break;

        case FLASH_SIZE_8M_MAP_512_512:
            rf_cal_sec = 256 - 5;
            break;

        case FLASH_SIZE_16M_MAP_512_512:
        case FLASH_SIZE_16M_MAP_1024_1024:
            rf_cal_sec = 512 - 5;
            break;

        case FLASH_SIZE_32M_MAP_512_512:
        case FLASH_SIZE_32M_MAP_1024_1024:
            rf_cal_sec = 1024 - 5;
            break;

        default:
            rf_cal_sec = 0;
            break;
    }

    return rf_cal_sec;
}

/**********************************SAMPLE CODE*****************************/
#define ETS_GPIO_INTR_ENABLE()  _xt_isr_unmask(1 << ETS_GPIO_INUM)  //ENABLE INTERRUPTS
#define ETS_GPIO_INTR_DISABLE() _xt_isr_mask(1 << ETS_GPIO_INUM)    //DISABLE INTERRUPTS


// Interrupt handler - looks at the accerometer data ready
// signal on pin INTR_PIN, and the configuration switch on BUTTON_IO_PIN
void gpio_intr_handler(uint8_t gpio_num)
{
  uint32 status = GPIO_REG_READ(GPIO_STATUS_ADDRESS);          //READ STATUS OF INTERRUPT
  static uint8 val = 0;

  if (status & INTR_PIN) {
    //printf("ISR - GPIO_%d\n",gpio_num);
    uint32_t now = xTaskGetTickCountFromISR();
    xQueueSendToBackFromISR(tsqueue, &now, NULL);
  }

  if (status & BUTTON_IO_PIN) {
    if (val == 0) {
      GPIO_OUTPUT_SET(LED_IO_NUM, 1);
      val = 1;
    } else {
      GPIO_OUTPUT_SET(LED_IO_NUM, 0);
      val = 0;
    }
  }


  //CLEAR THE STATUS IN THE W1 INTERRUPT REGISTER
  GPIO_REG_WRITE(GPIO_STATUS_W1TC_ADDRESS, status);       
}

void i2cScanTask(void *pvParameters) {
  uint8_t i;
  printf("i2cScanTask - SCL=GPIO%d, SDA=GPIO%d\n",SCL_PIN,SDA_PIN);
  i2c_init(SCL_PIN,SDA_PIN);
  printf("i2c_init() complete\n");

  while(1) {
    i = ADXL345_findDevice();
    printf("ADXL found at address %x\n",i);
    vTaskDelay(5000 / portTICK_RATE_MS);
  } 
}

/**
 * Initialise the ADXL345 accelerometer trip to use a FIFO buffer
 * and send an interrupt when the FIFO is full.
 */
void setup_adxl345() {
  uint8_t devAddr;
  
  printf("setup_adxl345()\n");
  
  // Initialise the ADXL345 i2c interface and search for the ADXL345
  devAddr = ADXL345_init(SCL_PIN,SDA_PIN);
  printf("ADXL345 found at address 0x%x\n",devAddr);
  
  //printf("Clearing Settings...\n");
  //ADXL345_clearSettings();
  
  // Bypass the FIFO buffer
  ADXL345_writeRegisterBit(ADXL345_REG_FIFO_CTL,6,0);
  ADXL345_writeRegisterBit(ADXL345_REG_FIFO_CTL,7,0);
  
  printf("Setting 4G range\n");
  ADXL345_setRange(ADXL345_RANGE_4G);
  
  printf("Setting to 100Hz data rate\n");
  ADXL345_setDataRate(ADXL345_DATARATE_100HZ);
  //ADXL345_setDataRate(ADXL345_DATARATE_12_5HZ);
  
  /*printf("Setting Data Format - interupts active low.\n");
    if (ADXL345_writeRegister8(ADXL345_REG_DATA_FORMAT,0x2B)==-1) {
    printf("*** Error setting Data Format ***\n");
    } else {
    printf("Data Format Set to 0x%02x\n",
    ADXL345_readRegister8(ADXL345_REG_DATA_FORMAT));
    }
  */
  // Set to 4g range, 4mg/LSB resolution, interrupts active high.
  ADXL345_writeRegister8(ADXL345_REG_DATA_FORMAT,0b00001001);
  
  printf("Starting Measurement\n");
  if (ADXL345_writeRegister8(ADXL345_REG_POWER_CTL,0x08)==-1) {
    printf("*** Error setting measurement Mode ***\n");
  } else {
    printf("Measurement Mode set to 0x%02x\n",ADXL345_readRegister8(ADXL345_REG_POWER_CTL));
  }
  
  
  printf("Enabling Data Ready Interrupt\n");
  if (ADXL345_writeRegister8(ADXL345_REG_INT_ENABLE,0x80)==-1) {
    printf("*** Error enabling interrupt ***\n");
  } else {
    printf("Interrupt Enabled - set to 0x%02x\n",
	   ADXL345_readRegister8(ADXL345_REG_INT_ENABLE));
  }
  
  
  printf("************************************\n");
  printf("*           setup_adxl345()        *\n");
  printf("DEV_ID=     0x%02x\n",ADXL345_readRegister8(ADXL345_REG_DEVID));
  printf("INT_SOURCE= 0x%02x\n",ADXL345_readRegister8(ADXL345_REG_INT_SOURCE));
  printf("BW_RATE=    0x%02x\n",ADXL345_readRegister8(ADXL345_REG_BW_RATE));
  printf("DATA_FORMAT=0x%02x\n",ADXL345_readRegister8(ADXL345_REG_DATA_FORMAT));
  printf("INT_ENABLE= 0x%02x\n",ADXL345_readRegister8(ADXL345_REG_INT_ENABLE));
  printf("INT_MAP=    0x%02x\n",ADXL345_readRegister8(ADXL345_REG_INT_MAP));
  printf("POWER_CTL=  0x%02x\n",ADXL345_readRegister8(ADXL345_REG_POWER_CTL));
  printf("************************************\n");
  
}


/**
 * monitor the ADXL345 regularly to check register states.
 * Assumes it has been initialised by calling setup_adxl345() before
 * this task is started.
 */
void monitorAdxl345Task(void *pvParameters) {
  ADXL345_IVector r;
  
  while(1) {
    printf("*****************************************\n");
    printf("*        Periodic Monitoring            *\n");
    printf("INT_ENABLE= 0x%02x\n",ADXL345_readRegister8(ADXL345_REG_INT_ENABLE));
    printf("INT_MAP=    0x%02x\n",ADXL345_readRegister8(ADXL345_REG_INT_MAP));
    printf("INT_SOURCE= 0x%02x\n",ADXL345_readRegister8(ADXL345_REG_INT_SOURCE));
    printf("FIFO_STATUS= %d\n",ADXL345_readRegister8(ADXL345_REG_FIFO_STATUS));
    //    printf("Interrupt Pin GPIO%d value = %d\n",INTR_PIN,gpio_read(INTR_PIN));
    printf("Interrupt Pin GPIO%d value = %d\n",INTR_PIN,GPIO_INPUT_GET(INTR_PIN));
    // Read the data from FIFO - we probably do not really want this!
    /*int i;
    for (i=0;i<33;i++) {
      r = ADXL345_readRaw();
      printf("r.x=%7d, r.y=%7d, r.z=%7d\n",r.XAxis,r.YAxis,r.ZAxis);
    }
    printf("INT_SOURCE= 0x%02x\n",ADXL345_readRegister8(ADXL345_REG_INT_SOURCE));
    printf("*****************************************\n");
    */
    vTaskDelay(3000 / portTICK_RATE_MS);
  }
}


void alarmCheckTask(void *pvParam) {
  static int dataUpdateCount = 0;
  static int lastAlarmState = 0;
  printf("AlarmCheckTask() - running every second\n");
  xQueueHandle *commsQueue = (xQueueHandle *)pvParam;
  while(1) {
    vTaskDelay(1000 / portTICK_RATE_MS);
    //printf("AlarmCheckTask() - heap=%d.\n", xPortGetFreeHeapSize());
    // Do FFT analysis if we have filled the buffer with data.
    if (anD.accDataFull) {
      // Analyse the collected data
      do_analysis();

      // Check if we have detected a fall event
      if (sdS.fallActive)
	check_fall();  // sets anD.fallDetected global variable.

      // Check the alarm state, and set the global anD.alarmState variable.
      alarm_check();
    
      // If no seizure detected, modify alarmState to reflect potential fall
      // detection
      if ((anD.alarmState == ALARM_STATE_OK) && (anD.fallDetected==1))
	anD.alarmState = ALARM_STATE_FALL;
    
      //  Display alarm message on screen.
      if (anD.alarmState == ALARM_STATE_OK) {
	APP_LOG(APP_LOG_LEVEL_DEBUG,"OK\n");
      }
      if (anD.alarmState == ALARM_STATE_WARN) {
	APP_LOG(APP_LOG_LEVEL_DEBUG,"WARNING\n");
      }
      if (anD.alarmState == ALARM_STATE_ALARM) {
	APP_LOG(APP_LOG_LEVEL_DEBUG,"**ALARM**\n");
      }
      if (anD.alarmState == ALARM_STATE_FALL) {
	APP_LOG(APP_LOG_LEVEL_DEBUG,"**FALL**\n");
      }
      if (anD.isManAlarm) {
	anD.alarmState = ALARM_STATE_MAN_ALARM;
	APP_LOG(APP_LOG_LEVEL_DEBUG,"** MAN ALARM**\n");
      }
      if (anD.isMuted) {
	anD.alarmState = ALARM_STATE_MUTE;
	APP_LOG(APP_LOG_LEVEL_DEBUG,"** MUTE **\n");
      }    
      
      // Send data to phone if we have an alarm condition.
      // or if alarm state has changed from last time.
      if ((anD.alarmState != ALARM_STATE_OK && !anD.isMuted) ||
	  (anD.alarmState != lastAlarmState)) {
	//sendSdData();
        xQueueSend(*commsQueue, &dataUpdateCount, 0);
      }
      lastAlarmState = anD.alarmState;
    }
  
    // See if it is time to send data to the phone.
    dataUpdateCount++;
    if (dataUpdateCount>=sdS.dataUpdatePeriod) {
      //sendSdData();
      xQueueSend(*commsQueue, &dataUpdateCount, 0);
      dataUpdateCount = 0;
    } 
  }
}




/* 
 *  Initialises the ADX345 accelerometer, 
 *  If USE_INTR is true,  waits for queue message from
 *  interrupt handler to say data is ready.
 *  Otherwise polls periodically to read data from the adxl345 FIFO
 */
void receiveAccelDataTask(void *pvParameters)
{
  ADXL345_IVector r;
  ADXL345_IVector buf[ACC_BUF_LEN];
  
  printf("receiveAccelDataTask - SCL=GPIO%d, SDA=GPIO%d\n",SCL_PIN,SDA_PIN);

  if (USE_INTR) {
    printf("SETUP INTERRUPT..\r\n");
    GPIO_ConfigTypeDef io_in_conf;
    io_in_conf.GPIO_IntrType = GPIO_PIN_INTR_POSEDGE;
    io_in_conf.GPIO_Mode = GPIO_Mode_Input;
    io_in_conf.GPIO_Pin = INTR_PIN;
    io_in_conf.GPIO_Pullup = GPIO_PullUp_EN;
    gpio_config(&io_in_conf);
    gpio_intr_handler_register(gpio_intr_handler, NULL);
    printf("Waiting for accelerometer data ready interrupt on gpio %d...\r\n", INTR_PIN);
  } else {
    printf("NOT using interrupts - will poll adxl345 periodically\n");
  }

  // Now initialise the adxl345 (which also initialises the i2c bus
  setup_adxl345();
  ADXL345_enableFifo();
  xQueueHandle *tsqueue = (xQueueHandle *)pvParameters;
  
  // Start the routine monitoring task
  //xTaskCreate(monitorAdxl345Task,"monitorAdxl345",256,NULL,2,NULL);
  
  while(1) {
    uint32_t data_ts;
    if (USE_INTR) {
      xQueueReceive(*tsqueue, &data_ts, portMAX_DELAY);
      printf("Accelerometer data ready....\n");
      data_ts *= portTICK_RATE_MS;
    } else {
      // Wait for 310 ms - 100Hz sample rate, fifo is 32 readings
      // so we wait for 31 readings = 310 ms.
      vTaskDelay(310 / portTICK_RATE_MS);
      int nFifo = ADXL345_readRegister8(ADXL345_REG_FIFO_STATUS);
      if (nFifo ==32) {
	printf("receiveAccelDataTask() - Warning - FIFO Overflow\n");
      } else {
	//printf("receiveAccelDataTask() - Reading data based on timer - %d readings\n",nFifo);
      }
      data_ts = 0;
    }
    
    /// Now read all the data from the FIFO buffer on the ADXL345.
    int i=0;
    bool finished = false;
    while (!finished) {
      r = ADXL345_readRaw();
      buf[i] = r;
      i++;
      //printf("%d:%d,  receiveAccelDataTask: %dms r.x=%7d, r.y=%7d, r.z=%7d\n",
      //     i,
      //     ADXL345_readRegister8(ADXL345_REG_FIFO_STATUS),
      //     data_ts,r.XAxis,r.YAxis,r.ZAxis);
      
      // have we emptied the fifo or filled our buffer yet?
      if ((ADXL345_readRegister8(ADXL345_REG_FIFO_STATUS)==0)
	  || (i==ACC_BUF_LEN)) finished = 1;
    }
    //printf("receiveAccelDataTask: read %d points from fifo, %dms r.x=%7d, r.y=%7d, r.z=%7d\n",
    //	   i,
    //	   data_ts,r.XAxis,r.YAxis,r.ZAxis);
    /*for (int n=0;n<i;n++) {
      printf("n=%d r.x=%7d, r.y=%7d, r.z=%7d\n",
      n,
      buf[n].XAxis,buf[n].YAxis,buf[n].ZAxis);
      }
    */

    // Call the acceleration handler in analysis.c
    accel_handler(buf,i);
  }
}



/******************************************************************************
 * FunctionName : user_init
 * Description  : entry of user application, init user function here
 * Parameters   : none
 * Returns      : none
 *******************************************************************************/
void user_init(void)
{

    wifi_set_opmode(NULL_MODE);
    wifi_set_sleep_type(MODEM_SLEEP_T);
    
    // Initial flashing of LED to prove it is alive!
    printf("LED Toggle using switch attached to GPIO12\n");
    GPIO_ConfigTypeDef io_out_conf;
    io_out_conf.GPIO_IntrType = GPIO_PIN_INTR_DISABLE;
    io_out_conf.GPIO_Mode = GPIO_Mode_Output;
    io_out_conf.GPIO_Pin = LED_IO_PIN;
    io_out_conf.GPIO_Pullup = GPIO_PullUp_DIS;
    gpio_config(&io_out_conf);

    GPIO_OUTPUT_SET(LED_IO_NUM, 0);  // LED On
    vTaskDelay(100);
    GPIO_OUTPUT_SET(LED_IO_NUM, 1);  // LED Off
    vTaskDelay(100);
    GPIO_OUTPUT_SET(LED_IO_NUM, 0);  // LED On
    vTaskDelay(100);

    GPIO_OUTPUT_SET(LED_IO_NUM, 1);  // LED Off
    vTaskDelay(100);
    GPIO_OUTPUT_SET(LED_IO_NUM, 0);   // LED On
    vTaskDelay(100);

    printf("SETUP switch INTERRUPT..\r\n");
    GPIO_ConfigTypeDef io_in_conf;
    io_in_conf.GPIO_IntrType = GPIO_PIN_INTR_NEGEDGE;
    io_in_conf.GPIO_Mode = GPIO_Mode_Input;
    io_in_conf.GPIO_Pin = BUTTON_IO_PIN;
    io_in_conf.GPIO_Pullup = GPIO_PullUp_EN;
    gpio_config(&io_in_conf);
    gpio_intr_handler_register(gpio_intr_handler, NULL);
    //ETS_GPIO_INTR_ENABLE();


    // reate the freeRTOS queues we use for comms between tasks
    tsqueue = xQueueCreate(2, sizeof(uint32_t));
    commsQueue = xQueueCreate(2, sizeof(uint32_t));


    //xTaskCreate(i2cScanTask,"i2cScan",256,NULL,2,NULL);

    settings_init();
    analysis_init();
    comms_init();
    // Start the routine monitoring task
    //xTaskCreate(monitorAdxl345Task,"monitorAdxl345",256,NULL,2,NULL);
    xTaskCreate(receiveAccelDataTask, "receiveAccelDataTask",
		256, &tsqueue, 2, NULL);
    xTaskCreate(alarmCheckTask, "AlarmCheckTask",
		512, &commsQueue, 2, NULL);

    xTaskCreate(commsTask, "CommsTask",
		512, &commsQueue, 2, NULL);
    
    
}

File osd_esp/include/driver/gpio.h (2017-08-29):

/*
 * ESPRSSIF MIT License
 *
 * Copyright (c) 2015 <ESPRESSIF SYSTEMS (SHANGHAI) PTE LTD>
 *
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
 */

#ifndef __GPIO_H__
#define __GPIO_H__
#include "esp8266/eagle_soc.h"
#ifdef __cplusplus
extern "C" {
#endif

#define GPIO_Pin_0              (BIT(0))  /* Pin 0 selected */
#define GPIO_Pin_1              (BIT(1))  /* Pin 1 selected */
#define GPIO_Pin_2              (BIT(2))  /* Pin 2 selected */
#define GPIO_Pin_3              (BIT(3))  /* Pin 3 selected */
#define GPIO_Pin_4              (BIT(4))  /* Pin 4 selected */
#define GPIO_Pin_5              (BIT(5))  /* Pin 5 selected */
#define GPIO_Pin_6              (BIT(6))  /* Pin 6 selected */
#define GPIO_Pin_7              (BIT(7))  /* Pin 7 selected */
#define GPIO_Pin_8              (BIT(8))  /* Pin 8 selected */
#define GPIO_Pin_9              (BIT(9))  /* Pin 9 selected */
#define GPIO_Pin_10             (BIT(10)) /* Pin 10 selected */
#define GPIO_Pin_11             (BIT(11)) /* Pin 11 selected */
#define GPIO_Pin_12             (BIT(12)) /* Pin 12 selected */
#define GPIO_Pin_13             (BIT(13)) /* Pin 13 selected */
#define GPIO_Pin_14             (BIT(14)) /* Pin 14 selected */
#define GPIO_Pin_15             (BIT(15)) /* Pin 15 selected */
#define GPIO_Pin_All            (0xFFFF)  /* All pins selected */

#define GPIO_PIN_REG_0          PERIPHS_IO_MUX_GPIO0_U
#define GPIO_PIN_REG_1          PERIPHS_IO_MUX_U0TXD_U
#define GPIO_PIN_REG_2          PERIPHS_IO_MUX_GPIO2_U
#define GPIO_PIN_REG_3          PERIPHS_IO_MUX_U0RXD_U
#define GPIO_PIN_REG_4          PERIPHS_IO_MUX_GPIO4_U
#define GPIO_PIN_REG_5          PERIPHS_IO_MUX_GPIO5_U
#define GPIO_PIN_REG_6          PERIPHS_IO_MUX_SD_CLK_U
#define GPIO_PIN_REG_7          PERIPHS_IO_MUX_SD_DATA0_U
#define GPIO_PIN_REG_8          PERIPHS_IO_MUX_SD_DATA1_U
#define GPIO_PIN_REG_9          PERIPHS_IO_MUX_SD_DATA2_U
#define GPIO_PIN_REG_10         PERIPHS_IO_MUX_SD_DATA3_U
#define GPIO_PIN_REG_11         PERIPHS_IO_MUX_SD_CMD_U
#define GPIO_PIN_REG_12         PERIPHS_IO_MUX_MTDI_U
#define GPIO_PIN_REG_13         PERIPHS_IO_MUX_MTCK_U
#define GPIO_PIN_REG_14         PERIPHS_IO_MUX_MTMS_U
#define GPIO_PIN_REG_15         PERIPHS_IO_MUX_MTDO_U

#define GPIO_PIN_REG(i) \
    (i==0) ? GPIO_PIN_REG_0:  \
    (i==1) ? GPIO_PIN_REG_1:  \
    (i==2) ? GPIO_PIN_REG_2:  \
    (i==3) ? GPIO_PIN_REG_3:  \
    (i==4) ? GPIO_PIN_REG_4:  \
    (i==5) ? GPIO_PIN_REG_5:  \
    (i==6) ? GPIO_PIN_REG_6:  \
    (i==7) ? GPIO_PIN_REG_7:  \
    (i==8) ? GPIO_PIN_REG_8:  \
    (i==9) ? GPIO_PIN_REG_9:  \
    (i==10)? GPIO_PIN_REG_10: \
    (i==11)? GPIO_PIN_REG_11: \
    (i==12)? GPIO_PIN_REG_12: \
    (i==13)? GPIO_PIN_REG_13: \
    (i==14)? GPIO_PIN_REG_14: \
    GPIO_PIN_REG_15

#define GPIO_PIN_ADDR(i)        (GPIO_PIN0_ADDRESS + i*4)

#define GPIO_ID_IS_PIN_REGISTER(reg_id) \
    ((reg_id >= GPIO_ID_PIN0) && (reg_id <= GPIO_ID_PIN(GPIO_PIN_COUNT-1)))

#define GPIO_REGID_TO_PINIDX(reg_id) ((reg_id) - GPIO_ID_PIN0)

typedef enum {
    GPIO_PIN_INTR_DISABLE = 0,      /**< disable GPIO interrupt */
    GPIO_PIN_INTR_POSEDGE = 1,      /**< GPIO interrupt type : rising edge */
    GPIO_PIN_INTR_NEGEDGE = 2,      /**< GPIO interrupt type : falling edge */
    GPIO_PIN_INTR_ANYEDGE = 3,      /**< GPIO interrupt type : bothe rising and falling edge */
    GPIO_PIN_INTR_LOLEVEL = 4,      /**< GPIO interrupt type : low level */
    GPIO_PIN_INTR_HILEVEL = 5       /**< GPIO interrupt type : high level */
} GPIO_INT_TYPE;

typedef enum {
    GPIO_Mode_Input = 0x0,          /**< GPIO mode : Input */
    GPIO_Mode_Out_OD,               /**< GPIO mode : Output_OD */
    GPIO_Mode_Output ,              /**< GPIO mode : Output */
    GPIO_Mode_Sigma_Delta ,         /**< GPIO mode : Sigma_Delta */
} GPIOMode_TypeDef;

typedef enum {
    GPIO_PullUp_DIS = 0x0,      /**< disable GPIO pullup */
    GPIO_PullUp_EN  = 0x1,      /**< enable GPIO pullup */
} GPIO_Pullup_IF;

typedef struct {
    uint16           GPIO_Pin;      /**< GPIO pin */
    GPIOMode_TypeDef GPIO_Mode;     /**< GPIO mode */
    GPIO_Pullup_IF   GPIO_Pullup;   /**< GPIO pullup */
    GPIO_INT_TYPE    GPIO_IntrType; /**< GPIO interrupt type */
} GPIO_ConfigTypeDef;

  // Added by GJ because compilation fails in C99 mode without it.
  // I do not know why these are not defined in this file in the Espressif version.
  // Used some information from http://cholla.mmto.org/esp8266/gpio/
  void gpio_config(GPIO_ConfigTypeDef *pGPIOConfig);
  void gpio_output_set(uint8_t set_mask, uint8_t clear_mask,
		       uint8_t enable_mask, uint8_t disable_mask);

/** \defgroup Driver_APIs Driver APIs
  * @brief Driver APIs
  */

/** @addtogroup Driver_APIs
  * @{
  */

/** \defgroup GPIO_Driver_APIs GPIO Driver APIs
  * @brief GPIO APIs
  */

/** @addtogroup GPIO_Driver_APIs
  * @{
  */
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

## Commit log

2017-05-20 Modified blinky sketch to work with current (may2017) NONOS sdk.
2017-06-02 Added photos of prototype modules
2017-06-03 Added i2c driver - does not quite compile yet - issue with gpio inerrupt disable/enable
    [case1.scad]
2017-06-03 Got it to compile with i2c code - not working yet though
    [user_main.c]
2017-06-04 Trying (and failing to get i2c working...). Going to try a different library next.
    [user_main.c]
2017-06-10 reconfigured to different GPIOs to make sure I didn't have a clash with something - I didn't!
    [user_main.c]
2017-06-17 A version that actually talks to an ADXL345 board - no pull up resistors etc. just Wemos D1 mini D1 (=GIPIO5)->SCL, D2 (=GPIO4)->SDA - at least we get a response from the board!
2017-06-19 Added ADXL345 library code based on Arduino library - it compiles but is not tested.
2017-06-23 i2c and adxl345 library appears to be working.
2017-06-23 Initialised to 100Hz by default.
2017-06-25 Working using interrupt to show data ready rather than polling.
2017-06-25 Moved interrupt pin to GPIO13 (D1 on Wemos D1 mini), added monitoring task to check if chip is working.
2017-06-25 Added loop in receiveAccelData Task to keep reading data until the interrupt clears - will be necessary for using FIFO.
2017-06-26 Added code to switch into FIFO mode
2017-06-26 Converted ADXL345_readRaw to return an integer16 vector rather than float for compatibility with Pebble_SD fixed point arithmetic.
    [adxl345.c, adxl345.h, osd_app.c]
2017-06-26 Feasibility study complete - ESP8266 connected to an ADXL345 accelerometer running the OpenSeizureDetector seizure detection algorithm - detects seizures in a simlar way to the Pebble Watch!
2017-06-27 Added httpd server code. Doesn't quite compile yet...
    [http_server.c, osd_app.c, osd_app.h]
2017-06-27 Added http server, and fixed crash when accelerometer is stationary - divide by zero calculationg power ratio.
    [http_server.c, osd_app.c, osd_app.h]
2017-06-27 http server functioning - accessing url /gpio?toggle=2 toggles the LED on and off!
2017-07-02 defined variables
    [case.scad, case1.scad]
2017-07-02 rounded cuboid
    [case.scad]
2017-07-02 subtract cuboid for battery
    [case.scad]
2017-07-02 modify case
    [case.scad]
2017-07-02 separate battery and circuit compartments
    [case.scad]
2017-07-02 usb port
    [case.scad]
2017-07-02 lugs added
    [case.scad, dimensions.scad]
2017-07-02 Added simple server for testing
    [TestRiskDownload.xls, namesdemo.xls]
2017-07-04 Added SPIFFS file system to save and retrieve settings. Had to comment out httpd server though because it was crashing - suspect running out of memory problem...
    [osd_app.c, osd_app.h, settings.c]
2017-07-04 Increased size of httpd task stack (because I got a task stack overflow error)
    [http_server.c, osd_app.c, osd_app.h]
2017-07-09 Fixed setup/run mode using switch on SETUP_PIN GPIO line.
    [case1.scad]
2017-07-12 Moved comms to its own task to prevent it blocking alarm check.
    [osd_app.c, osd_app.h]
2017-07-16 Added Laura's watch case 3d model
    [textTest.scad]
2017-07-17 Added sleep_test, which is an ESP RTOS SDK based wifi demo - needs modifying to check we can put board into MODEM_SLEEP mode successfully
2017-07-18 Added sample wifi_station_machine_demo which includes modem_sleep from espressif examples.
2017-07-24 Espressif SDK test of MODEM_SLEEP mode - it works! current switche from 79mA to 25mA!
2017-08-09 Started osd_esp that is based on Espressif RTOS sdk - just reads setup/run switch and toggles LED to prove we can read and write to GPIO.
2017-08-20 Added esp_test app, which is just a LED blinking app to prove we can use GPIO
2017-08-20 Added GPIOtest, which is an Espressif RTOS SDK LED blink demo
2017-08-20 Added previous version of i2c library - plan is to convert that to Espressif SDK
2017-08-27 Converted esp-open-rtos i2c driver to work with espressif sdk - compiles but not tested yet.
2017-08-28 Appears to be detecting adxl345 correctly - progress!
    [i2c.c, user_main.c]
2017-08-28 Accelerometer appears to be working - not sure about FIFO interrupt though
2017-08-28 Got accelerometer reading working by polling FIFO - not sure why interrupts aren't working.
2017-08-28 Converted to work in C99 mode - had to define some prototypes that are missing in gpio.h etc.
    [adxl345.h, gpio.h, i2c.c]
2017-08-29 Moved adxl345 code to driver folders
2017-08-30 Added AlarmCheckTask to do analysis periodically and determine the alarm state for the device.
